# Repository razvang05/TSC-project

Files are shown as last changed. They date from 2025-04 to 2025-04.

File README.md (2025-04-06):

# TSC-project

**Author: Razvan Gheorghe 334CA**

## • Diagrama Bloc
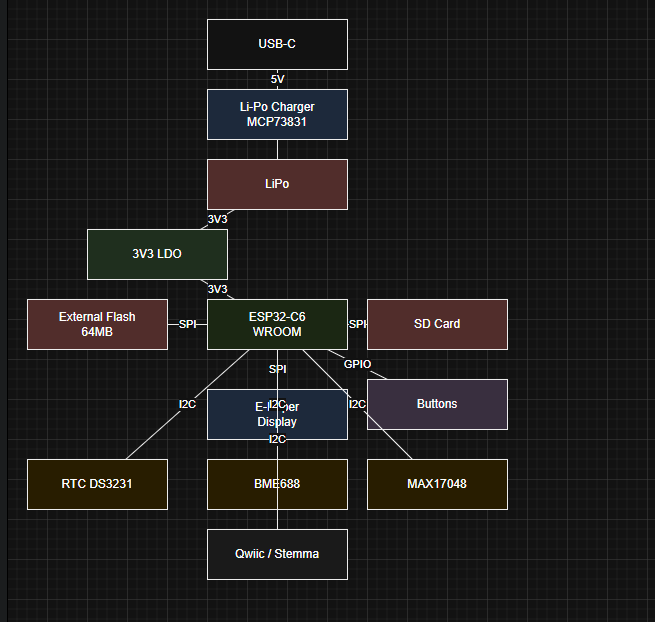
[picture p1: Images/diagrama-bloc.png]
Diagrama Bloc


## • BOM (Bill of Materials)

**Note:** TP-urile au fost construite de mine.

  | Nr. | Component Name | Procurement Link | Datasheet Link |
  |-----|----------------|------------------|----------------|
  | 1 | BOOT_BUTON | [Link](https://www.snapeda.com/parts/EVQP7L01P/Panasonic%20Electronic%20Components/view-part/?welcome=home) | [Datasheet](https://www.snapeda.com/parts/EVQP7L01P/Panasonic/datasheet/) |
  | 2 | C1 | [Link](https://componentsearchengine.com/part-view/CC0402MRX5R5BB106/YAGEO) | [Datasheet](https://componentsearchengine.com/Datasheets/2/CC0402MRX5R5BB106.pdf) |
  | 3 | C1_BAT | [Link](https://componentsearchengine.com/part-view/CC0402MRX5R5BB106/YAGEO) | [Datasheet](https://componentsearchengine.com/Datasheets/2/CC0402MRX5R5BB106.pdf) |
  | 4 | C1_BAT2 | [Link](https://componentsearchengine.com/part-view/CC0402MRX5R5BB106/YAGEO) | [Datasheet](https://componentsearchengine.com/Datasheets/2/CC0402MRX5R5BB106.pdf) |
  | 5 | C2 | [Link](https://componentsearchengine.com/part-view/CC0402MRX5R5BB106/YAGEO) | [Datasheet](https://componentsearchengine.com/Datasheets/2/CC0402MRX5R5BB106.pdf) |
  | 6 | C2_BAT | [Link](https://componentsearchengine.com/part-view/CC0402MRX5R5BB106/YAGEO) | [Datasheet](https://componentsearchengine.com/Datasheets/2/CC0402MRX5R5BB106.pdf) |
  | 7 | C3 | [Link](https://componentsearchengine.com/part-view/CC0402MRX5R5BB106/YAGEO) | [Datasheet](https://componentsearchengine.com/Datasheets/2/CC0402MRX5R5BB106.pdf) |
  | 8 | C4 | [Link](https://componentsearchengine.com/part-view/CC0402MRX5R5BB106/YAGEO) | [Datasheet](https://componentsearchengine.com/Datasheets/2/CC0402MRX5R5BB106.pdf) |
  | 9 | C4_USB | [Link](https://componentsearchengine.com/part-view/CC0402MRX5R5BB106/YAGEO) | [Datasheet](https://componentsearchengine.com/Datasheets/2/CC0402MRX5R5BB106.pdf) |
  | 10 | C5 | [Link](https://componentsearchengine.com/part-view/CC0402MRX5R5BB106/YAGEO) | [Datasheet](https://componentsearchengine.com/Datasheets/2/CC0402MRX5R5BB106.pdf) |
  | 11 | C5_USB | [Link](https://componentsearchengine.com/part-view/CC0402MRX5R5BB106/YAGEO) | [Datasheet](https://componentsearchengine.com/Datasheets/2/CC0402MRX5R5BB106.pdf) |
  | 12 | C6 | [Link](https://componentsearchengine.com/part-view/CC0402MRX5R5BB106/YAGEO) | [Datasheet](https://componentsearchengine.com/Datasheets/2/CC0402MRX5R5BB106.pdf) |
  | 13 | C7 | [Link](https://componentsearchengine.com/part-view/CC0402MRX5R5BB106/YAGEO) | [Datasheet](https://componentsearchengine.com/Datasheets/2/CC0402MRX5R5BB106.pdf) |
  | 14 | C8 | [Link](https://componentsearchengine.com/part-view/CC0402MRX5R5BB106/YAGEO) | [Datasheet](https://componentsearchengine.com/Datasheets/2/CC0402MRX5R5BB106.pdf) |
  | 15 | C9 | [Link](https://componentsearchengine.com/part-view/CC0402MRX5R5BB106/YAGEO) | [Datasheet](https://componentsearchengine.com/Datasheets/2/CC0402MRX5R5BB106.pdf) |
  | 16 | C10 | [Link](https://componentsearchengine.com/part-view/CC0402MRX5R5BB106/YAGEO) | [Datasheet](https://componentsearchengine.com/Datasheets/2/CC0402MRX5R5BB106.pdf) |
  | 17 | C10_SUPERCAR | [Link](https://industry.panasonic.com/global/en/products/control/switch/light-touch/number/evqpuj02k) | [Datasheet](https://industry.panasonic.com/global/en/downloads?tab=catalog&small_g_cd=203&part_no=EVQPUJ02K) |
  | 18 | CHANGE_BUTTON | [Link](https://www.snapeda.com/parts/EVQP7L01P/Panasonic%20Electronic%20Components/view-part/?welcome=home) | [Datasheet](https://www.snapeda.com/parts/EVQP7L01P/Panasonic/datasheet/) |
  | 19 | C_DELAY | [Link](https://componentsearchengine.com/part-view/CC0402MRX5R5BB106/YAGEO) | [Datasheet](https://componentsearchengine.com/Datasheets/2/CC0402MRX5R5BB106.pdf) |
  | 20 | D1 | [Link](https://www.snapeda.com/parts/USBLC6-2SC6Y/STMicroelectronics/view-part/?ref=eda) | [Datasheet](https://www.snapeda.com/parts/USBLC6-2SC6Y/STMicroelectronics/view-part/?ref=eda) |
  | 21 | D2 | [Link](https://ro.mouser.com/ProductDetail/KYOCERA-AVX/SD0805S020S1R0?qs=jCA%252BPfw4LHbpkAoSnwrdjw%3D%3D) | [Datasheet](https://ro.mouser.com/datasheet/2/40/schottky-3165252.pdf) |
  | 22 | D3 | [Link](https://ro.mouser.com/ProductDetail/KYOCERA-AVX/SD0805S020S1R0?qs=jCA%252BPfw4LHbpkAoSnwrdjw%3D%3D) | [Datasheet](https://ro.mouser.com/datasheet/2/40/schottky-3165252.pdf) |
  | 23 | D4 | [Link](https://ro.mouser.com/ProductDetail/KYOCERA-AVX/SD0805S020S1R0?qs=jCA%252BPfw4LHbpkAoSnwrdjw%3D%3D) | [Datasheet](https://ro.mouser.com/datasheet/2/40/schottky-3165252.pdf) |
  | 24 | D5 | [Link](https://ro.mouser.com/ProductDetail/KYOCERA-AVX/SD0805S020S1R0?qs=jCA%252BPfw4LHbpkAoSnwrdjw%3D%3D) | [Datasheet](https://ro.mouser.com/datasheet/2/40/schottky-3165252.pdf) |
  | 25 | D6 | [Link](https://www.snapeda.com/parts/PGB1010603MR/Littelfuse/view-part/?ref=eda) | [Datasheet](https://www.snapeda.com/parts/PGB1010603MR/Littelfuse%20Inc./datasheet/) |
  | 26 | D7 | [Link](https://ro.mouser.com/ProductDetail/KYOCERA-AVX/SD0805S020S1R0?qs=jCA%252BPfw4LHbpkAoSnwrdjw%3D%3D) | [Datasheet](https://ro.mouser.com/datasheet/2/40/schottky-3165252.pdf) |
  | 27 | D8 | [Link](https://www.snapeda.com/parts/PGB1010603MR/Littelfuse/view-part/?ref=eda) | [Datasheet](https://www.snapeda.com/parts/PGB1010603MR/Littelfuse%20Inc./datasheet/) |
  | 28 | D9 | [Link](https://www.snapeda.com/parts/PGB1010603MR/Littelfuse/view-part/?ref=eda) | [Datasheet](https://www.snapeda.com/parts/PGB1010603MR/Littelfuse%20Inc./datasheet/) |
  | 29 | D10 | [Link](https://www.snapeda.com/parts/PGB1010603MR/Littelfuse/view-part/?ref=eda) | [Datasheet](https://www.snapeda.com/parts/PGB1010603MR/Littelfuse%20Inc./datasheet/) |
  | 30 | D11 | [Link](https://www.snapeda.com/parts/PGB1010603MR/Littelfuse/view-part/?ref=eda) | [Datasheet](https://www.snapeda.com/parts/PGB1010603MR/Littelfuse%20Inc./datasheet/) |
  | 31 | D12 | [Link](https://www.snapeda.com/parts/PGB1010603MR/Littelfuse/view-part/?ref=eda) | [Datasheet](https://www.snapeda.com/parts/PGB1010603MR/Littelfuse%20Inc./datasheet/) |
  | 32 | EPD_C1 | [Link](https://componentsearchengine.com/part-view/CC0402MRX5R5BB106/YAGEO) | [Datasheet](https://componentsearchengine.com/Datasheets/2/CC0402MRX5R5BB106.pdf) |
  | 33 | EPD_C2 | [Link](https://componentsearchengine.com/part-view/CC0402MRX5R5BB106/YAGEO) | [Datasheet](https://componentsearchengine.com/Datasheets/2/CC0402MRX5R5BB106.pdf) |
  | 34 | EPD_C5 | [Link](https://componentsearchengine.com/part-view/CC0402MRX5R5BB106/YAGEO) | [Datasheet](https://componentsearchengine.com/Datasheets/2/CC0402MRX5R5BB106.pdf) |
  | 35 | EPD_C6 | [Link](https://componentsearchengine.com/part-view/CC0402MRX5R5BB106/YAGEO) | [Datasheet](https://componentsearchengine.com/Datasheets/2/CC0402MRX5R5BB106.pdf) |
  | 36 | EPD_C7 | [Link](https://componentsearchengine.com/part-view/CC0402MRX5R5BB106/YAGEO) | [Datasheet](https://componentsearchengine.com/Datasheets/2/CC0402MRX5R5BB106.pdf) |
  | 37 | EPD_C8 | [Link](https://componentsearchengine.com/part-view/CC0402MRX5R5BB106/YAGEO) | [Datasheet](https://componentsearchengine.com/Datasheets/2/CC0402MRX5R5BB106.pdf) |
  | 38 | EPD_C9 | [Link](https://componentsearchengine.com/part-view/CC0402MRX5R5BB106/YAGEO) | [Datasheet](https://componentsearchengine.com/Datasheets/2/CC0402MRX5R5BB106.pdf) |
  | 39 | EPD_C10 | [Link](https://componentsearchengine.com/part-view/CC0402MRX5R5BB106/YAGEO) | [Datasheet](https://componentsearchengine.com/Datasheets/2/CC0402MRX5R5BB106.pdf) |
  | 40 | EPD_C11 | [Link](https://componentsearchengine.com/part-view/CC0402MRX5R5BB106/YAGEO) | [Datasheet](https://componentsearchengine.com/Datasheets/2/CC0402MRX5R5BB106.pdf) |
  | 41 | EPD_C12 | [Link](https://componentsearchengine.com/part-view/CC0402MRX5R5BB106/YAGEO) | [Datasheet](https://componentsearchengine.com/Datasheets/2/CC0402MRX5R5BB106.pdf) |
  | 42 | IC1 | [Link](https://componentsearchengine.com/part-view/BD5229G-TR/ROHM%20Semiconductor) | [Datasheet](https://datasheet.datasheetarchive.com/originals/distributors/Datasheets_SAMA/f2b9741ef86007909f138d561a359946.pdf) |
  | 43 | IC4 | [Link](https://componentsearchengine.com/part-view/XC6220A331MR-G/Torex) | [Datasheet](https://product.torexsemi.com/system/files/series/xc6220.pdf) |
  | 44 | J1 | [Link](https://componentsearchengine.com/part-view/FH34SRJ-24S-0.5SH(99)/Hirose) | [Datasheet](https://www.hirose.com/en/product/document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) |
  | 45 | J2 | [Link](https://componentsearchengine.com/part-view/USB4110-GF-A/GCT%20(GLOBAL%20CONNECTOR%20TECHNOLOGY)) | [Datasheet](https://gct.co/files/drawings/usb4110.pdf) |
  | 46 | J3 | [Link](https://www.snapeda.com/parts/PRT-14417/SparkFun/view-part/) | [Datasheet](https://www.snapeda.com/parts/PRT-14417/SparkFun%20Electronics/datasheet/) |
  | 47 | J4 | [Link](https://www.snapeda.com/parts/112A-TAAR-R03/Attend/view-part/) | [Datasheet](https://www.snapeda.com/parts/112A-TAAR-R03/Attend/datasheet/) |
  | 48 | MCP73831 | [Link](https://ro.mouser.com/ProductDetail/Microchip-Technology/MCP73831T-2ACI-OT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) | [Datasheet](https://ro.mouser.com/datasheet/2/268/MCP73831_Family_Data_Sheet_DS20001984H-3441711.pdf) |
  | 49 | L1 | [Link](https://ro.mouser.com/ProductDetail/Wurth-Elektronik/744043680?qs=PGXP4M47uW6VkZq%252BkzjrHA%3D%3D) | [Datasheet](https://www.we-online.com/components/products/datasheet/744043680.pdf) |
  | 50 | PFMF.050.1 | [Link](https://ro.mouser.com/ProductDetail/EPCOS-TDK/B72520T0350K062?qs=dEfas%2FXlABIszF52uu7vrg%3D%3D) | [Datasheet](https://www.tdk-electronics.tdk.com/inf/75/db/CTVS_14/Surge_protection_series.pdf) |
  | 51 | Q1 | [Link](https://componentsearchengine.com/part-view/DMG2305UX-7/Diodes%20Incorporated) | [Datasheet](https://www.diodes.com//assets/Datasheets/DMG2305UX.pdf) |
  | 52 | Q2 | [Link](https://componentsearchengine.com/part-view/DMG2305UX-7/Diodes%20Incorporated) | [Datasheet](https://www.diodes.com//assets/Datasheets/DMG2305UX.pdf) |
  | 53 | Q3 | [Link](https://componentsearchengine.com/part-view/SI1308EDL-T1-GE3/Vishay) | [Datasheet](https://componentsearchengine.com/part-view/SI1308EDL-T1-GE3/Vishay) |
  | 54 | R1 | [Link](https://componentsearchengine.com/part-view/R0402%201%25%20100%20K%20(RC0402FR-07100KL)/YAGEO) | [Datasheet](https://www.yageo.com/upload/media/product/products/datasheet/rchip/PYu-RC_Group_51_RoHS_L_12.pdf) |
  | 55 | R1_PINH | [Link](https://componentsearchengine.com/part-view/R0402%201%25%20100%20K%20(RC0402FR-07100KL)/YAGEO) | [Datasheet](https://www.yageo.com/upload/media/product/products/datasheet/rchip/PYu-RC_Group_51_RoHS_L_12.pdf) |
  | 56 | R1_PINH1 | [Link](https://componentsearchengine.com/part-view/R0402%201%25%20100%20K%20(RC0402FR-07100KL)/YAGEO) | [Datasheet](https://www.yageo.com/upload/media/product/products/datasheet/rchip/PYu-RC_Group_51_RoHS_L_12.pdf) |
  | 57 | R1_BAT | [Link](https://componentsearchengine.com/part-view/R0402%201%25%20100%20K%20(RC0402FR-07100KL)/YAGEO) | [Datasheet](https://www.yageo.com/upload/media/product/products/datasheet/rchip/PYu-RC_Group_51_RoHS_L_12.pdf) |
  | 58 | R1_PWRUSB | [Link](https://componentsearchengine.com/part-view/R0402%201%25%20100%20K%20(RC0402FR-07100KL)/YAGEO) | [Datasheet](https://www.yageo.com/upload/media/product/products/datasheet/rchip/PYu-RC_Group_51_RoHS_L_12.pdf) |
  | 59 | R2 | [Link](https://componentsearchengine.com/part-view/R0402%201%25%20100%20K%20(RC0402FR-07100KL)/YAGEO) | [Datasheet](https://www.yageo.com/upload/media/product/products/datasheet/rchip/PYu-RC_Group_51_RoHS_L_12.pdf) |
  | 60 | R2_PINH | [Link](https://componentsearchengine.com/part-view/R0402%201%25%20100%20K%20(RC0402FR-07100KL)/YAGEO) | [Datasheet](https://www.yageo.com/upload/media/product/products/datasheet/rchip/PYu-RC_Group_51_RoHS_L_12.pdf) |
  | 61 | R2-PINH1 | [Link](https://componentsearchengine.com/part-view/R0402%201%25%20100%20K%20(RC0402FR-07100KL)/YAGEO) | [Datasheet](https://www.yageo.com/upload/media/product/products/datasheet/rchip/PYu-RC_Group_51_RoHS_L_12.pdf) |
  | 62 | R2 | [Link](https://componentsearchengine.com/part-view/R0402%201%25%20100%20K%20(RC0402FR-07100KL)/YAGEO) | [Datasheet](https://www.yageo.com/upload/media/product/products/datasheet/rchip/PYu-RC_Group_51_RoHS_L_12.pdf) |
  | 63 | R2-PINH | [Link](https://componentsearchengine.com/part-view/R0402%201%25%20100%20K%20(RC0402FR-07100KL)/YAGEO) | [Datasheet](https://www.yageo.com/upload/media/product/products/datasheet/rchip/PYu-RC_Group_51_RoHS_L_12.pdf) |
  | 64 | R2-PINH1 | [Link](https://componentsearchengine.com/part-view/R0402%201%25%20100%20K%20(RC0402FR-07100KL)/YAGEO) | [Datasheet](https://www.yageo.com/upload/media/product/products/datasheet/rchip/PYu-RC_Group_51_RoHS_L_12.pdf) |
  | 65 | R2_USB | [Link](https://componentsearchengine.com/part-view/R0402%201%25%20100%20K%20(RC0402FR-07100KL)/YAGEO) | [Datasheet](https://www.yageo.com/upload/media/product/products/datasheet/rchip/PYu-RC_Group_51_RoHS_L_12.pdf) |
  | 66 | R2_USB | [Link](https://componentsearchengine.com/part-view/R0402%201%25%20100%20K%20(RC0402FR-07100KL)/YAGEO) | [Datasheet](https://www.yageo.com/upload/media/product/products/datasheet/rchip/PYu-RC_Group_51_RoHS_L_12.pdf) |
  | 67 | R2_USB1 | [Link](https://componentsearchengine.com/part-view/R0402%201%25%20100%20K%20(RC0402FR-07100KL)/YAGEO) | [Datasheet](https://www.yageo.com/upload/media/product/products/datasheet/rchip/PYu-RC_Group_51_RoHS_L_12.pdf) |
  | 68 | R3 | [Link](https://componentsearchengine.com/part-view/R0402%201%25%20100%20K%20(RC0402FR-07100KL)/YAGEO) | [Datasheet](https://www.yageo.com/upload/media/product/products/datasheet/rchip/PYu-RC_Group_51_RoHS_L_12.pdf) |
  | 69 | R4 | [Link](https://componentsearchengine.com/part-view/R0402%201%25%20100%20K%20(RC0402FR-07100KL)/YAGEO) | [Datasheet](https://www.yageo.com/upload/media/product/products/datasheet/rchip/PYu-RC_Group_51_RoHS_L_12.pdf) |
  | 70 | R5 | [Link](https://componentsearchengine.com/part-view/R0402%201%25%20100%20K%20(RC0402FR-07100KL)/YAGEO) | [Datasheet](https://www.yageo.com/upload/media/product/products/datasheet/rchip/PYu-RC_Group_51_RoHS_L_12.pdf) |
  | 71 | R6 | [Link](https://componentsearchengine.com/part-view/R0402%201%25%20100%20K%20(RC0402FR-07100KL)/YAGEO) | [Datasheet](https://www.yageo.com/upload/media/product/products/datasheet/rchip/PYu-RC_Group_51_RoHS_L_12.pdf) |
  | 72 | R7 | [Link](https://componentsearchengine.com/part-view/R0402%201%25%20100%20K%20(RC0402FR-07100KL)/YAGEO) | [Datasheet](https://www.yageo.com/upload/media/product/products/datasheet/rchip/PYu-RC_Group_51_RoHS_L_12.pdf) |
  | 73 | R8 | [Link](https://componentsearchengine.com/part-view/R0402%201%25%20100%20K%20(RC0402FR-07100KL)/YAGEO) | [Datasheet](https://www.yageo.com/upload/media/product/products/datasheet/rchip/PYu-RC_Group_51_RoHS_L_12.pdf) |
  | 74 | R9 | [Link](https://componentsearchengine.com/part-view/R0402%201%25%20100%20K%20(RC0402FR-07100KL)/YAGEO) | [Datasheet](https://www.yageo.com/upload/media/product/products/datasheet/rchip/PYu-RC_Group_51_RoHS_L_12.pdf) |
  | 75 | R10 | [Link](https://componentsearchengine.com/part-view/R0402%201%25%20100%20K%20(RC0402FR-07100KL)/YAGEO) | [Datasheet](https://www.yageo.com/upload/media/product/products/datasheet/rchip/PYu-RC_Group_51_RoHS_L_12.pdf) |
  | 76 | RESET_BUTTON | [Link](https://www.snapeda.com/parts/EVQP7L01P/Panasonic%20Electronic%20Components/view-part/?welcome=home) | [Datasheet](https://www.snapeda.com/parts/EVQP7L01P/Panasonic/datasheet/) |
  | 77 | R_BOOT | [Link](https://componentsearchengine.com/part-view/R0402%201%25%20100%20K%20(RC0402FR-07100KL)/YAGEO) | [Datasheet](https://www.yageo.com/upload/media/product/products/datasheet/rchip/PYu-RC_Group_51_RoHS_L_12.pdf) |
  | 78 | R_CAPACITOR | [Link](https://componentsearchengine.com/part-view/R0402%201%25%20100%20K%20(RC0402FR-07100KL)/YAGEO) | [Datasheet](https://www.yageo.com/upload/media/product/products/datasheet/rchip/PYu-RC_Group_51_RoHS_L_12.pdf) |
  | 79 | R_CHANGE | [Link](https://componentsearchengine.com/part-view/R0402%201%25%20100%20K%20(RC0402FR-07100KL)/YAGEO) | [Datasheet](https://www.yageo.com/upload/media/product/products/datasheet/rchip/PYu-RC_Group_51_RoHS_L_12.pdf) |
  | 80 | R_CL1 | [Link](https://componentsearchengine.com/part-view/R0402%201%25%20100%20K%20(RC0402FR-07100KL)/YAGEO) | [Datasheet](https://www.yageo.com/upload/media/product/products/datasheet/rchip/PYu-RC_Group_51_RoHS_L_12.pdf) |
  | 81 | R_RESET | [Link](https://componentsearchengine.com/part-view/R0402%201%25%20100%20K%20(RC0402FR-07100KL)/YAGEO) | [Datasheet](https://www.yageo.com/upload/media/product/products/datasheet/rchip/PYu-RC_Group_51_RoHS_L_12.pdf) |
  | 82 | SENSOR2 | [Link](https://www.snapeda.com/parts/BME680/Bosch/view-part/?welcome=home) | [Datasheet](https://www.snapeda.com/parts/BME680/Bosch%20Sensortec/datasheet/) |
  | 83 | SJ1 | [Link](https://grabcad.com/library/solder-jumpers-1) | [Datasheet](https://grabcad.com/library/solder-jumpers-1) |
  | 84 | TP1 | [Link](nan) | [Datasheet](nan) |
  | 85 | TP2 | [Link](nan) | [Datasheet](nan) |
  | 86 | TP3 | [Link](nan) | [Datasheet](nan) |
  | 87 | TP4 | [Link](nan) | [Datasheet](nan) |
  | 88 | TP5 | [Link](nan) | [Datasheet](nan) |
  | 89 | TP6 | [Link](nan) | [Datasheet](nan) |
  | 90 | TP7 | [Link](nan) | [Datasheet](nan) |
  | 91 | TP8 | [Link](nan) | [Datasheet](nan) |
  | 92 | TP9 | [Link](nan) | [Datasheet](nan) |
  | 93 | TP10 | [Link](nan) | [Datasheet](nan) |
  | 94 | TP11 | [Link](nan) | [Datasheet](nan) |
  | 95 | TP12 | [Link](nan) | [Datasheet](nan) |
  | 96 | TP13 | [Link](nan) | [Datasheet](nan) |
  | 97 | TP14 | [Link](nan) | [Datasheet](nan) |
  | 98 | TP15 | [Link](nan) | [Datasheet](nan) |
  | 99 | TP16 | [Link](nan) | [Datasheet](nan) |
  | 100 | TP17 | [Link](nan) | [Datasheet](nan) |
  | 101 | U1 | [Link](https://www.snapeda.com/parts/W25Q512JVEIQ/Winbond+Electronics/view-part/?ref=eda) | [Datasheet](https://www.snapeda.com/parts/W25Q512JVEIQ/Winbond+Electronics/view-part/?ref=eda) |
  | 102 | U2 | [Link](https://www.snapeda.com/parts/ESP32-C6-WROOM-1-N8/Espressif+Systems/view-part/?ref=eda) | [Datasheet](https://www.snapeda.com/parts/ESP32-C6-WROOM-1-N8/Espressif%20Systems/datasheet/) |
  | 103 | U3 | [Link](https://www.snapeda.com/parts/DS3231SN%23/Analog+Devices/view-part/?ref=eda) | [Datasheet](https://www.snapeda.com/parts/DS3231SN%23/Analog%20Devices/datasheet/) |
  | 104 | U4 | [Link](https://www.snapeda.com/parts/MAX17048G+T10/Analog+Devices/view-part/?ref=eda) | [Datasheet](https://www.snapeda.com/parts/MAX17048G+T10/Analog%20Devices/datasheet/) |

  ## ⚙️ Hardware Functionality Description

Dispozitivul eBook Reader este un sistem portabil de citire a cărților electronice, construit în jurul modulului **ESP32-C6-WROOM-1-N8**. Acesta integrează următoarele componente și module:

### 🔌 Module și Funcționalitate

- **ESP32-C6-WROOM-1-N8** — Microcontroler principal cu Wi-Fi și BLE integrat; gestionează comunicația, senzorii și afișajul.
- **BME688** — Senzor de calitate a aerului și mediu (temperatură, umiditate, presiune, gaz); conectat prin magistrala **I2C**.
- **DS3231SN** — Modul RTC de înaltă precizie pentru menținerea timpului real; conectat la ESP32 prin **I2C**.
- **MAX17048** — Monitor de nivel al bateriei cu interfață **I2C**, oferă estimarea SOC (state of charge).
- **SD Card Module** — Pentru stocarea locală a datelor colectate; conectat prin **SPI**.
- **Display E-Ink** — Afișaj cu consum redus de energie, interfață **SPI**, include semnale EPD_CS, EPD_DC, EPD_RST, EPD_BUSY.
- **Memorie NOR Flash W25Q512JVEIQ (64MB)** — Conectată prin **SPI** pentru stocarea firmware-ului sau datelor mari.
- **Buton BOOT și RESET** — Control GPIO pentru bootloader și resetare sistem.
- **MCP73831** — Controler pentru încărcare acumulator Li-Po, conectat direct la baterie.
- **LDO XC6220A331MR-G** — Regulator de tensiune 3.3V pentru alimentarea circuitelor logice.
- **Port USB-C (USB4110-GF-A)** — Alimentare și interfață serială pentru upload cod și debugging.

### 🔧 Interfețe de Comunicație

| Interfață | Componente conectate |
|---|---|
| I2C | BME688, MAX17048, DS3231SN |
| SPI | E-Ink Display, SD Card, Flash Memory |
| UART | Serial debug prin USB-C (TX/RX) |
| GPIO | Butoane, LED-uri, semnale control |

### ⚡ Energie și Alimentare

- Alimentarea se face prin **USB-C** sau baterie Li-Po.
- Planul de masă este aplicat pe ambele straturi (TOP & BOTTOM).
- Se folosesc **condensatori de decuplare 100nF** aproape de fiecare pin de alimentare al IC-urilor.
- Regulatorul LDO oferă 3.3V, iar controlerul MCP73831 gestionează încărcarea bateriei.
- Funcțiile de **low-power sleep** ale ESP32 sunt folosite pentru a reduce consumul în standby.

## 📌 ESP32-C6 Pin Mapping

| Pin ESP32-C6 | Componentă Legată | Funcție |
|---|---|---|
| GPIO0 | Flash Memory (DI) | SPI MOSI |
| GPIO1 | Flash Memory (DO) | SPI MISO |
| GPIO2 | Flash CS | Chip Select |
| GPIO3 | Flash HOLD | Hold/Reset |
| GPIO6 | E-Ink Display (EPD_DC)  | Data/Command Select  |
| GPIO7 | E-Ink Display (EPD_CS)  | Chip Select |
| GPIO8 | E-Ink Display (EPD_RST) | Reset |
| GPIO9 | E-Ink Display (BUSY) | Status Feedback |
| GPIO10 | SD Card (CS) | Chip Select |
| GPIO11 | SD Card (MOSI) | Data In |
| GPIO12 | SD Card (MISO) | Data Out |
| GPIO13 | SD Card (CLK) | Clock |
| GPIO16/17 | UART | Serial TX / RX |
| GPIO18/19 | I2C | SDA / SCL |
| GPIO20 | MAX17048 Alert | Battery Warning |

## 🧩 Alte Elemente Relevante pentru Review

- **Design Log**: Înregistrări ale deciziilor de proiectare, erori întâlnite și soluții aplicate.
- **Imagini randate 3D**: Prezentate în folderul `Images/` și în secțiunea `Mechanical/`.
- **Plasarea componentelor**: Respectă fișierul de recomandări mecanice, inclusiv alinierea cu carcasa.
- **Carcasa și Modelul 3D**: Include model complet în Fusion360 și export `.step`, în `Mechanical/`.
- **Test Pad-uri**: Clar etichetate în silkscreen, prezente pentru semnalele relevante (MOSI, MISO, Rx, etc.).
- **Silkscreen**: Numele componentelor sunt vizibile și nu sunt suprapuse peste pad-uri.

---

> Toate aceste aspecte sunt conforme cu cerințele OpenBook și ghidurile din laborator. Design-ul a fost verificat prin ERC & DRC, cu toate erorile relevante rezolvate.

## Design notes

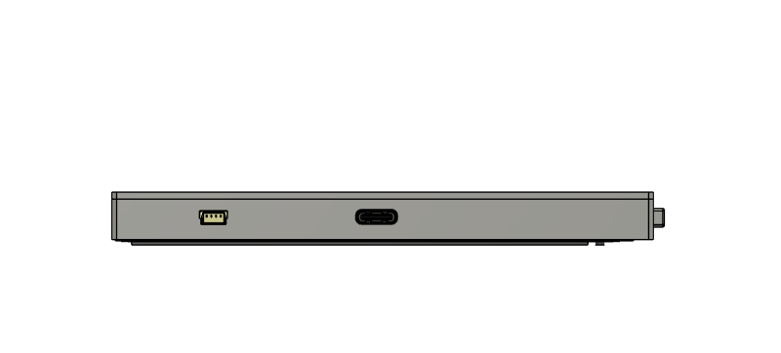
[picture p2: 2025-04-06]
Images/right.png

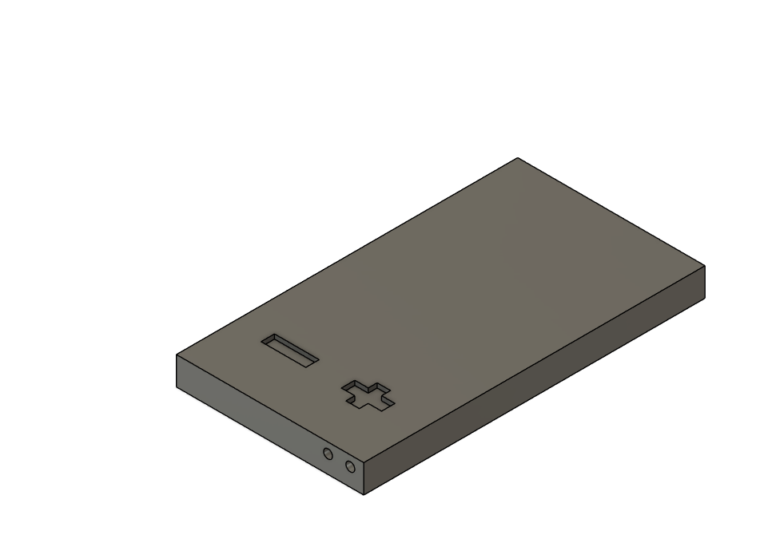
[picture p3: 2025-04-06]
Images/battery.png

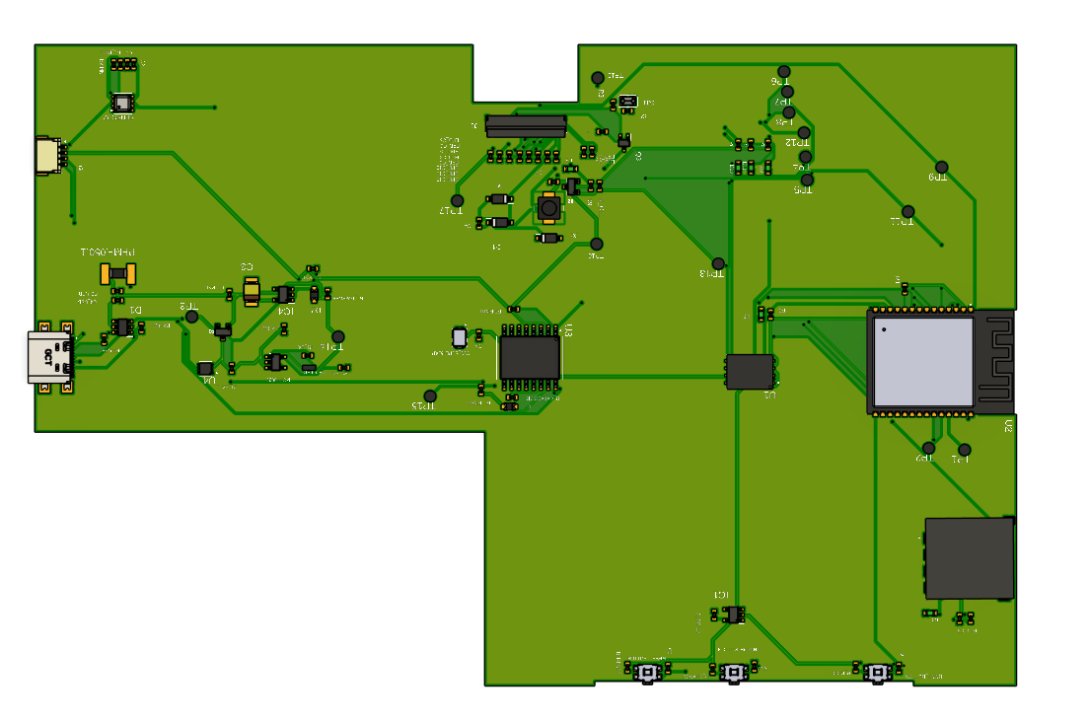
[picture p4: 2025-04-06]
Images/pcb_top.png

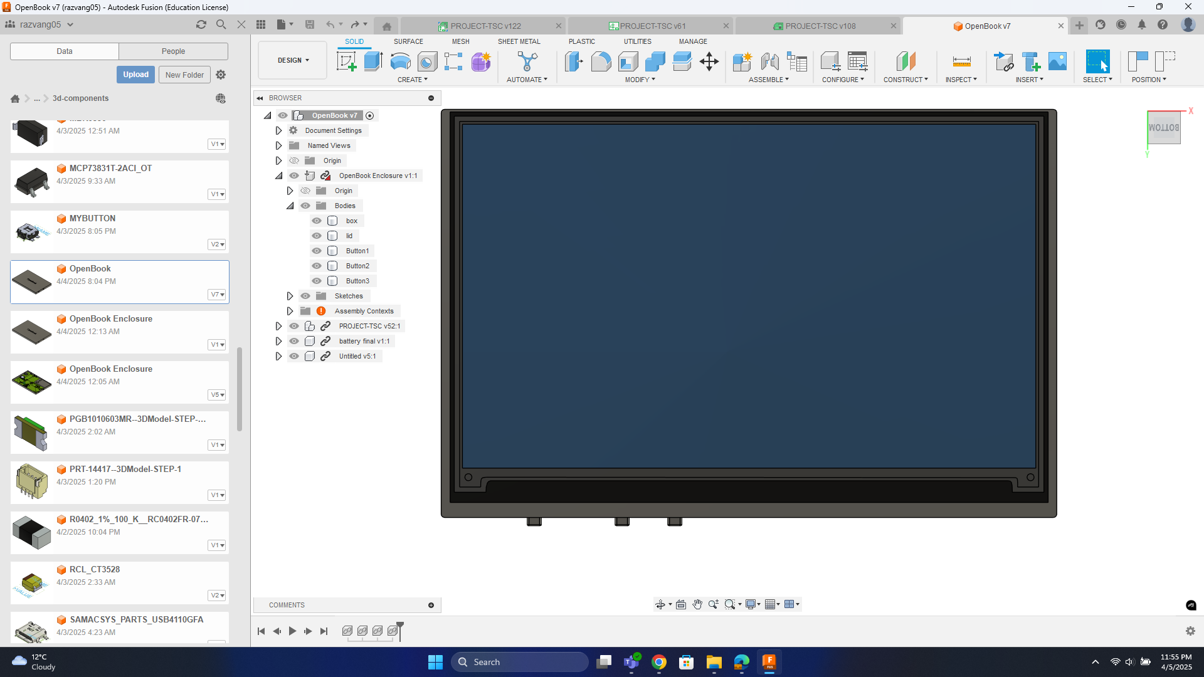
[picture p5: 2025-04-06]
Images/bottom_ebook.png

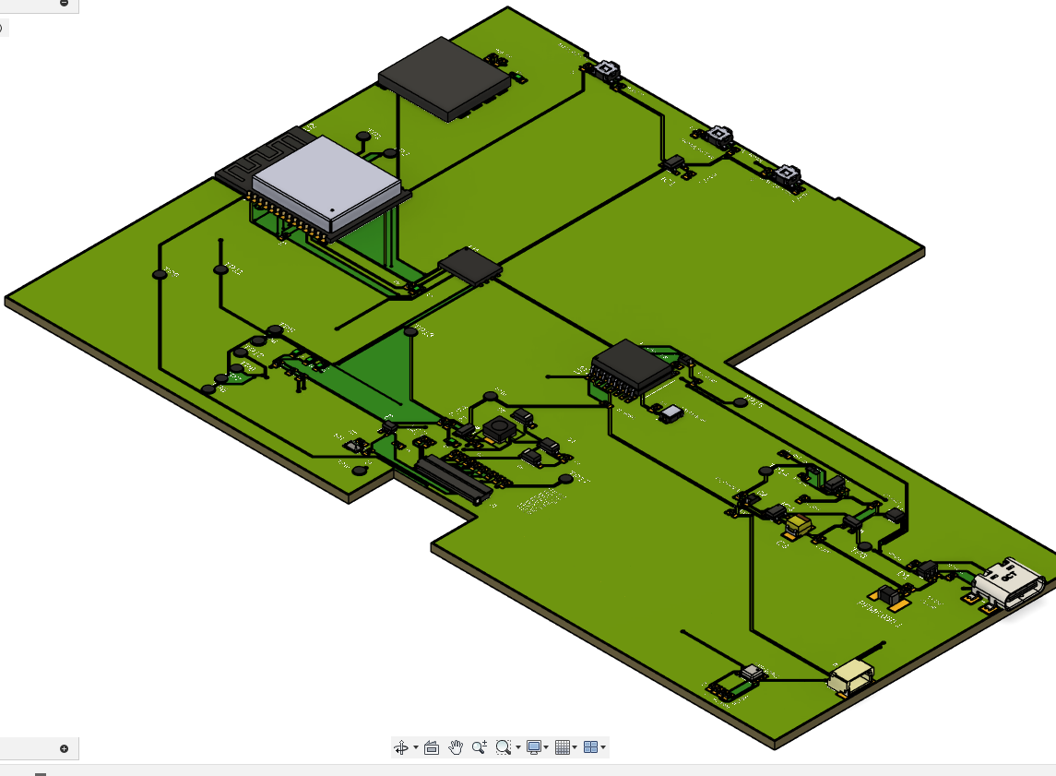
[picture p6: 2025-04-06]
Images/pcb.png

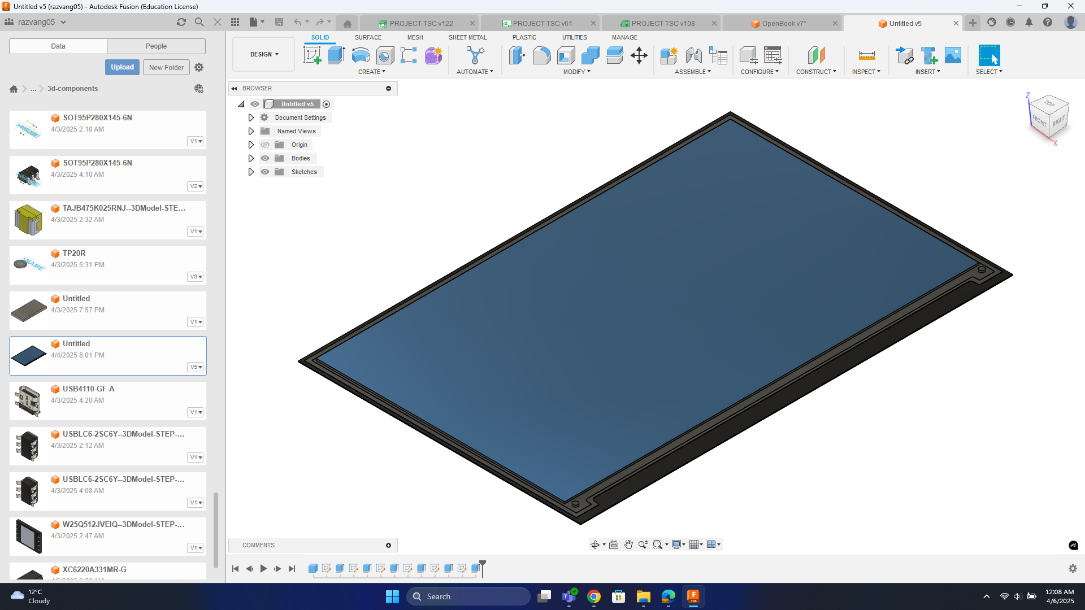
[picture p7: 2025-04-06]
Images/display.png

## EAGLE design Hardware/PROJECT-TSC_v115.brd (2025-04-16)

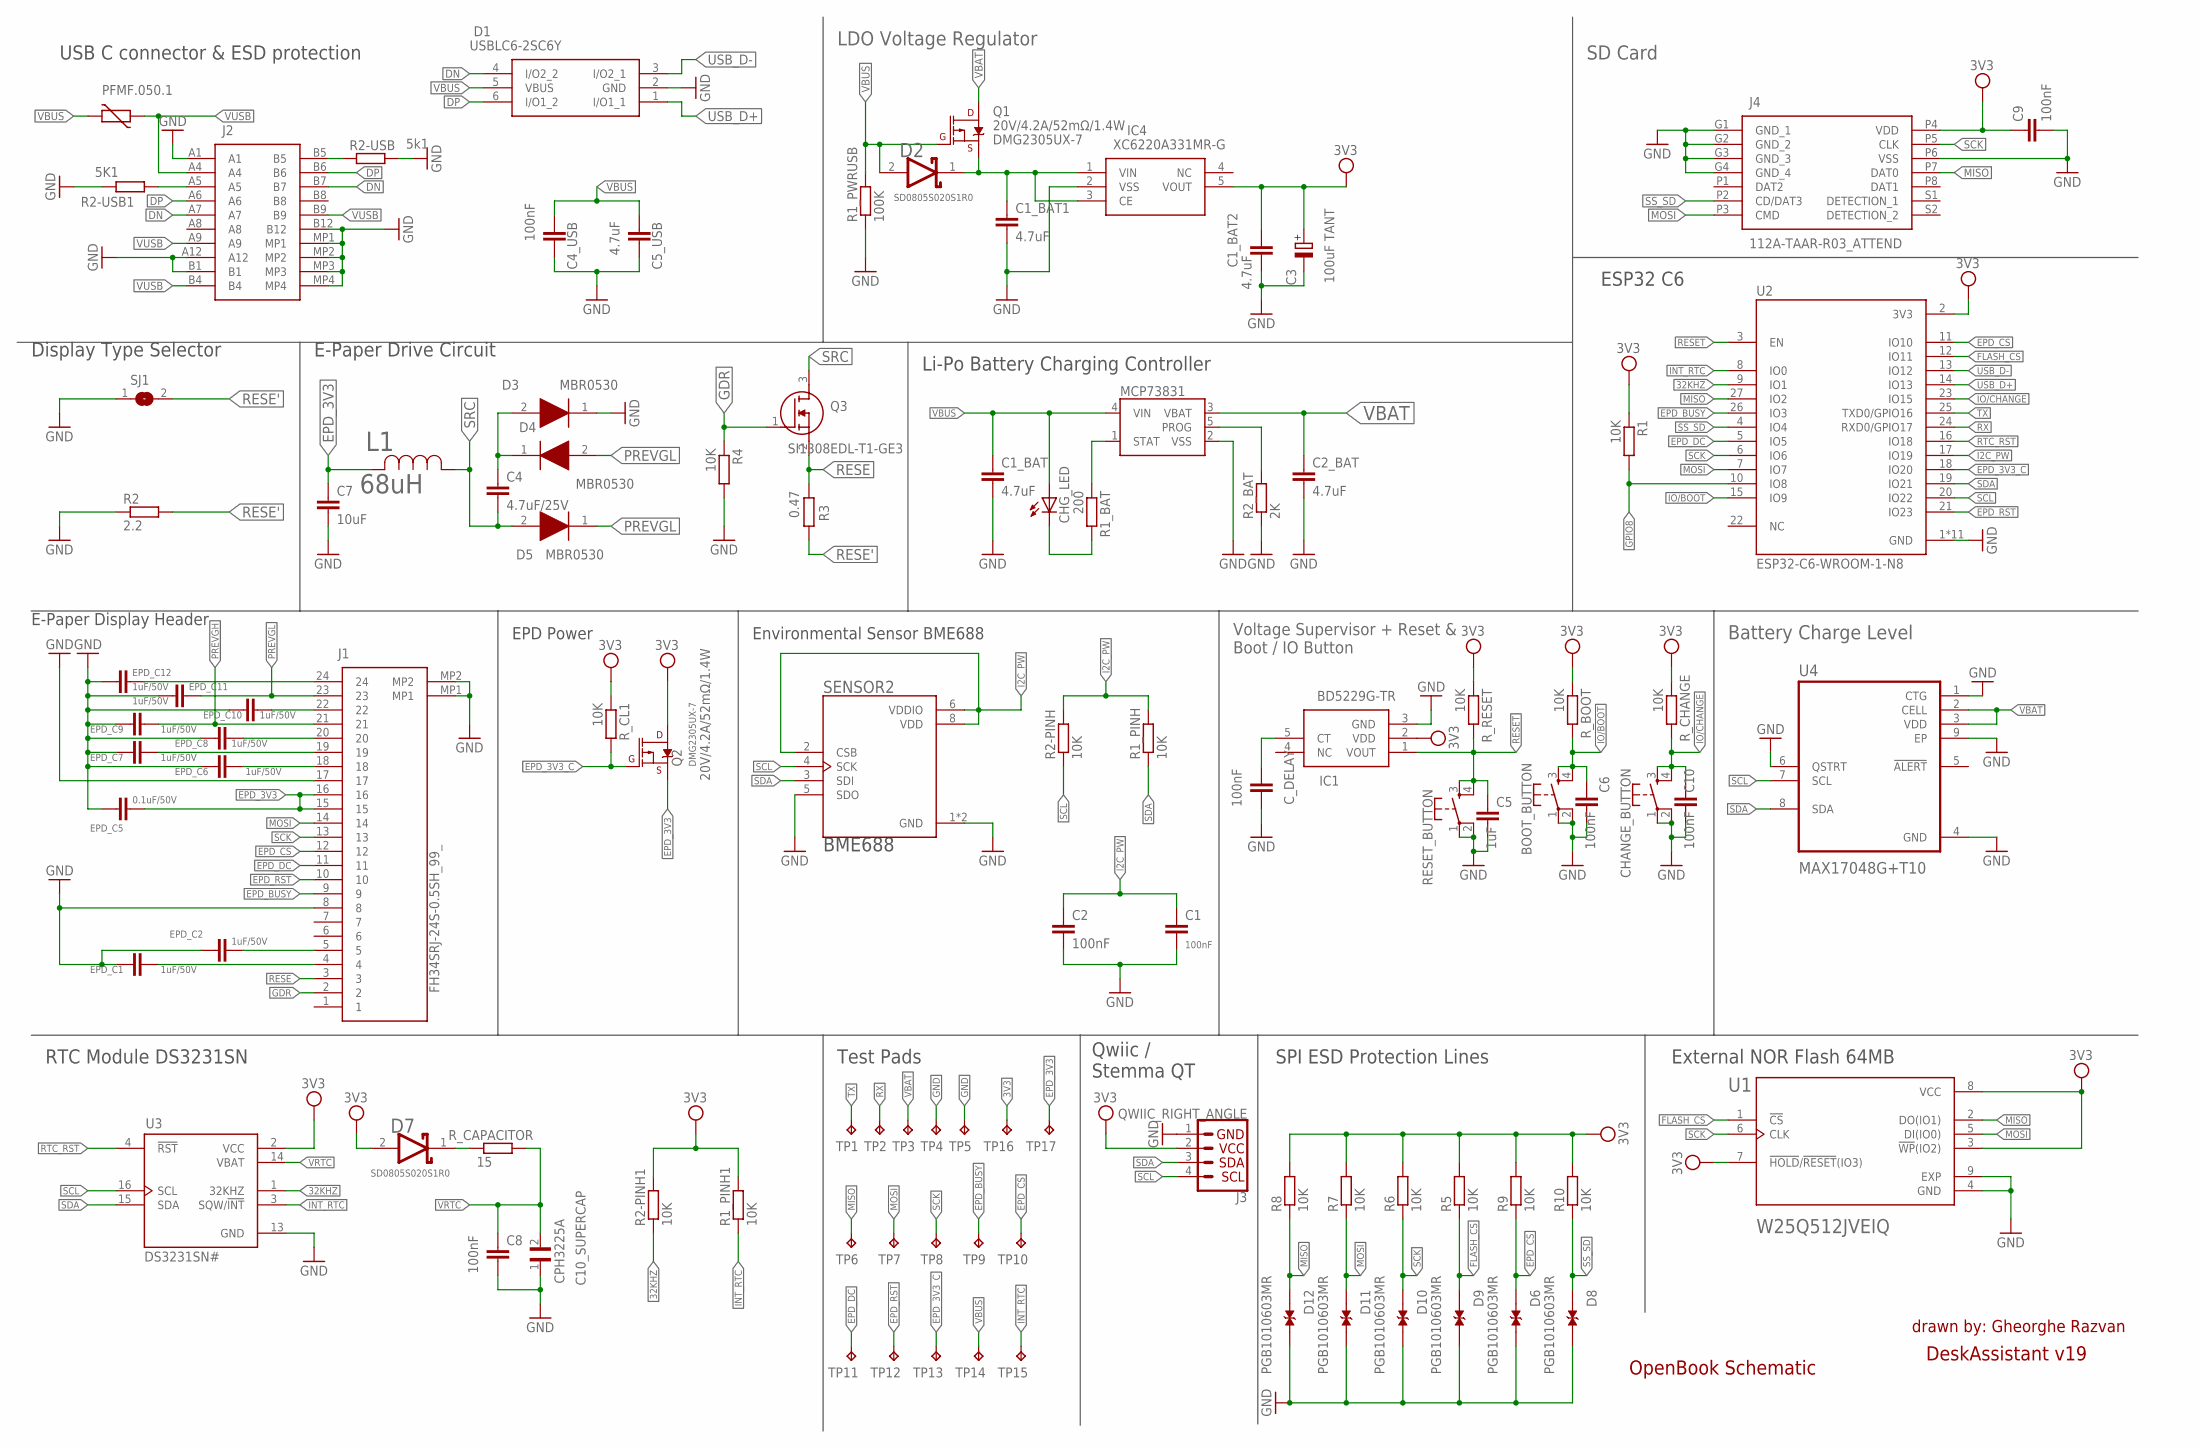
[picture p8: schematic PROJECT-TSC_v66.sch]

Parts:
BOOT_BUTTON: BUTTON_CUSYOMV1; MYBUTTON
C1, C2, C4_USB, C6, C8, C9, C10: 100nF; EAGLE-LTSPICE_C0402
C1_BAT, C1_BAT1, C1_BAT2, C2_BAT, C5_USB: 4.7uF; EAGLE-LTSPICE_C0402
C3: 100uF TANT; RCL_CT3528
C4: 4.7uF/25V; EAGLE-LTSPICE_C0402
C5: 1uF; EAGLE-LTSPICE_C0402
C7: 10uF; EAGLE-LTSPICE_C0402
C10_SUPERCAP: CPH3225A; CAPCP3225X100N
CHANGE_BUTTON: BUTTON_CUSYOMV1; MYBUTTON
CHG_LED: ADAFRUIT_LEDCHIP-LED0603; ADAFRUIT_CHIP-LED0603
C_DELAY: 100nF; EAGLE-LTSPICE_C0402
D1: USBLC6-2SC6Y; SOT95P280X145-6N
D2, D7: ESP32_WROVER_AVX---SD0805S020S1R0_AVX_SD0805S020S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; ESP32_WROVER_AVX---SD0805S020S1R0_AVX_SD0805S020S1R0_0
D3, D4, D5: MBR0530; SOD3716X135N
D6, D8, D9, D10, D11, D12: PGB1010603MR; DIOC1608X36N
EPD_C1, EPD_C2, EPD_C6, EPD_C7, EPD_C8, EPD_C9, EPD_C10, EPD_C11, EPD_C12: 1uF/50V; EAGLE-LTSPICE_C0402
EPD_C5: 0.1uF/50V; EAGLE-LTSPICE_C0402
IC1: BD5229G-TR; SOT95P280X120-5N
IC4: XC6220A331MR-G; SOT95P280X120-5N
J1: FH34SRJ-24S-0.5SH_99_; FH34SRJ24S05SH99
J2: SAMACSYS_PARTS_USB4110-GF-A; SAMACSYS_PARTS_USB4110GFA
J3: QWIIC_RIGHT_ANGLE; JST04_1MM_RA
J4: 112A-TAAR-R03_ATTEND; 112ATAARR03ATTEND
L1: 68uH; IND_4828-WE-TPC_WRE
MCP73831: ESP32_WROVER_SPARKFUN-IC-POWER_MCP73831; ESP32_WROVER_SPARKFUN-IC-POWER_SOT23-5
PFMF.050.1: ESP32C6_VARISTORCN1812; ESP32C6_VARISTOR_CT/CN1812
Q1, Q2: 20V/4.2A/52mΩ/1.4W; ESP32_WROVER_SPARKFUN-DISCRETESEMI_SOT23-3
Q3: SI1308EDL-T1-GE3; SOT65P210X110-3N
R1, R1_PINH, R1_PINH1, R2-PINH, R2-PINH1, R4, R5, R6, R7, R8, R9, R10: 10K; ESP32_WROVER_EAGLE-LTSPICE_R0402
R1_BAT: 200; ESP32_WROVER_EAGLE-LTSPICE_R0402
R1_PWRUSB: 100K; ESP32_WROVER_EAGLE-LTSPICE_R0402
R2: 2.2; ESP32_WROVER_EAGLE-LTSPICE_R0402
R2-USB: 5k1; ESP32_WROVER_EAGLE-LTSPICE_R0402
R2-USB1: 5K1; ESP32_WROVER_EAGLE-LTSPICE_R0402
R2_BAT: 2K; ESP32_WROVER_EAGLE-LTSPICE_R0402
R3: 0.47; ESP32_WROVER_EAGLE-LTSPICE_R0402
RESET_BUTTON: BUTTON_CUSYOMV1; MYBUTTON
R_BOOT: 10K; ESP32_WROVER_EAGLE-LTSPICE_R0402
R_CAPACITOR: 15; ESP32_WROVER_EAGLE-LTSPICE_R0402
R_CHANGE: 10K; ESP32_WROVER_EAGLE-LTSPICE_R0402
R_CL1: 10K; ESP32_WROVER_EAGLE-LTSPICE_R0402
R_RESET: 10K; ESP32_WROVER_EAGLE-LTSPICE_R0402
SENSOR2: ESP32_WROVER_BME680_BME680; ESP32_WROVER_BME680_PSON80P300X300X100-8N
SJ1: SJ
TP1, TP2, TP3, TP4, TP5, TP6, TP7, TP8, TP9, TP10, TP11, TP12, TP13, TP14, TP15, TP16, TP17: TPTP20R; TP20R
U1: W25Q512JVEIQ; SON127P600X800X80-9N
U2: ESP32-C6-WROOM-1-N8; XCVR_ESP32-C6-WROOM-1-N8
U3: DS3231SN#; SOIC127P1032X265-16N
U4: MAX17048G+T10; SON50P200X200X80-9N

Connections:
3V3: C1_BAT2.1, C3.+, C9.1, D7.2 (ANODE), IC1.2 (VDD), IC4.5 (VOUT), J3.2, J4.P4 (VDD), Q2.3 (D), R1.1, R1_PINH1.2, R2-PINH1.2, R5.2, R6.2, R7.2, R8.2, R9.2, R10.2, R_BOOT.1, R_CHANGE.1, R_CL1.1, R_RESET.1, TP16.TP, U1.3 (!WP!(IO2)), U1.7 (!HOLD!/!RESET!(IO3)), U1.8 (VCC), U2.2 (3V3), U3.2 (VCC)
32KHZ: R2-PINH1.1, U2.9 (IO1), U3.1 (32KHZ)
DN: D1.4 (I/O2_2), J2.A7, J2.B7
DP: D1.6 (I/O1_2), J2.A6, J2.B6
EPD_3V3: C7.1, EPD_C5.1, J1.15, J1.16, L1.2, Q2.2 (S), TP17.TP
EPD_3V3_C: Q2.1 (G), R_CL1.2, TP13.TP, U2.18 (IO20)
EPD_BUSY: J1.9, TP9.TP, U2.26 (IO3)
EPD_CS: D6.1, J1.12, R9.1, TP10.TP, U2.11 (IO10)
EPD_DC: J1.11, TP11.TP, U2.5 (IO5)
EPD_RST: J1.10, TP12.TP, U2.21 (IO23)
FLASH_CS: D9.1, R5.1, U1.1 (!CS), U2.12 (IO11)
GDR: J1.2, Q3.1 (G), R4.1
GND: BOOT_BUTTON.1, BOOT_BUTTON.2, C1.2, C1_BAT.2, C1_BAT1.2, C1_BAT2.2, C2.2, C2_BAT.2, C3.-, C4_USB.2, C5.2, C5_USB.2, C6.2, C7.2, C8.2, C9.2, C10.2, C10_SUPERCAP.1, CHANGE_BUTTON.1, CHANGE_BUTTON.2, C_DELAY.2, D1.2 (GND), D3.1 (K), D6.2, D8.2, D9.2, D10.2, D11.2, D12.2, EPD_C1.2, EPD_C2.2, EPD_C5.2, EPD_C6.2, EPD_C7.2, EPD_C8.2, EPD_C9.2, EPD_C10.2, EPD_C11.2, EPD_C12.2, IC1.3 (GND), IC4.2 (VSS), J1.8, J1.17, J1.MP1, J1.MP2, J2.A1, J2.A12, J2.B1, J2.B12, J2.MP1, J2.MP2, J2.MP3, J2.MP4, J3.1, J4.G1 (GND_1), J4.G2 (GND_2), J4.G3 (GND_3), J4.G4 (GND_4), J4.P6 (VSS), MCP73831.2 (VSS), R1_PWRUSB.1, R2.1, R2-USB.2, R2-USB1.1, R2_BAT.1, R4.2, RESET_BUTTON.1, RESET_BUTTON.2, SENSOR2.1 (GND), SENSOR2.5 (SDO), SENSOR2.7 (GND), SJ1.1, TP4.TP, TP5.TP, U1.4 (GND), U1.9 (EXP), U2.1 (GND), U2.28 (GND), U2.29_1 (GND), U2.29_2 (GND), U2.29_3 (GND), U2.29_4 (GND), U2.29_5 (GND), U2.29_6 (GND), U2.29_7 (GND), U2.29_8 (GND), U2.29_9 (GND), U3.13 (GND), U4.1 (CTG), U4.4 (GND), U4.6 (QSTRT), U4.9 (EP)
GPIO8: R1.2, U2.10 (IO8)
I2C_PW: C1.1, C2.1, R1_PINH.2, R2-PINH.2, SENSOR2.2 (CSB), SENSOR2.6 (VDDIO), SENSOR2.8 (VDD), U2.17 (IO19)
INT_RTC: R1_PINH1.1, TP15.TP, U2.8 (IO0), U3.3 (SQW/!INT)
IO/BOOT: BOOT_BUTTON.3, BOOT_BUTTON.4, C6.1, R_BOOT.2, U2.15 (IO9)
IO/CHANGE: C10.1, CHANGE_BUTTON.3, CHANGE_BUTTON.4, R_CHANGE.2, U2.23 (IO15)
MISO: D12.1, J4.P7 (DAT0), R8.1, TP6.TP, U1.2 (DO(IO1)), U2.27 (IO2)
MOSI: D11.1, J1.14, J4.P3 (CMD), R7.1, TP7.TP, U1.5 (DI(IO0)), U2.7 (IO7)
unnamed: J2.A5, R2-USB1.2
unnamed: J2.B5, R2-USB.1
unnamed: C1_BAT1.1, D2.1 (CATHODE), IC4.1 (VIN), IC4.3 (CE), Q1.2 (S)
unnamed: C4.1, D3.2 (A), D4.1 (K)
unnamed: C_DELAY.1, IC1.5 (CT)
unnamed: CHG_LED.C, R1_BAT.2
unnamed: MCP73831.1 (STAT), R1_BAT.1
unnamed: EPD_C1.1, J1.4
unnamed: MCP73831.5 (PROG), R2_BAT.2
unnamed: EPD_C2.1, J1.5
unnamed: D7.1 (CATHODE), R_CAPACITOR.1
unnamed: EPD_C8.1, J1.20
unnamed: EPD_C7.1, J1.19
unnamed: EPD_C6.1, J1.18
unnamed: EPD_C10.1, J1.22
unnamed: EPD_C12.1, J1.24
PREVGH: EPD_C9.1, J1.21
PREVGL: D4.2 (A), D5.1 (K), EPD_C11.1, J1.23
RESE: J1.3, Q3.2 (S), R3.1
RESE': R2.2, R3.2, SJ1.2
RESET: C5.1, IC1.1 (VOUT), RESET_BUTTON.3, RESET_BUTTON.4, R_RESET.2, U2.3 (EN)
RTC_RST: U2.16 (IO18), U3.4 (!RST)
RX: TP2.TP, U2.24 (RXD0/GPIO17)
SCK: D10.1, J1.13, J4.P5 (CLK), R6.1, TP8.TP, U1.6 (CLK), U2.6 (IO6)
SCL: J3.4, R2-PINH.1, SENSOR2.4 (SCK), U2.20 (IO22), U3.16 (SCL), U4.7 (SCL)
SDA: J3.3, R1_PINH.1, SENSOR2.3 (SDI), U2.19 (IO21), U3.15 (SDA), U4.8 (SDA)
SRC: C4.2, D5.2 (A), L1.1, Q3.3 (D)
SS_SD: D8.1, J4.P2 (CD/DAT3), R10.1, U2.4 (IO4)
TX: TP1.TP, U2.25 (TXD0/GPIO16)
USB_D+: D1.1 (I/O1_1), U2.14 (IO13)
USB_D-: D1.3 (I/O2_1), U2.13 (IO12)
VBAT: C2_BAT.1, MCP73831.3 (VBAT), Q1.3 (D), TP3.TP, U4.2 (CELL), U4.3 (VDD)
VBUS: C1_BAT.1, C4_USB.1, C5_USB.1, CHG_LED.A, D1.5 (VBUS), D2.2 (ANODE), MCP73831.4 (VIN), PFMF.050.1.2, Q1.1 (G), R1_PWRUSB.2, TP14.TP
VRTC: C8.1, C10_SUPERCAP.2, R_CAPACITOR.2, U3.14 (VBAT)
VUSB: J2.A4, J2.A9, J2.B4, J2.B9, PFMF.050.1.1

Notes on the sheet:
USB C connector & ESD protection
LDO Voltage Regulator
SD Card
Display Type Selector
E-Paper Drive Circuit
Li-Po Battery Charging Controller
ESP32 C6
E-Paper Display Header
EPD Power
Environmental Sensor BME688
BME688
RTC Module DS3231SN
Test Pads
Qwiic / Stemma QT
SPI ESD Protection Lines
External NOR Flash 64MB
Battery Charge Level
Voltage Supervisor + Reset & Boot / IO Button
OpenBook Schematic
drawn by: Gheorghe Razvan
DeskAssistant v19
DMG2305UX-7
SD0805S020S1R0

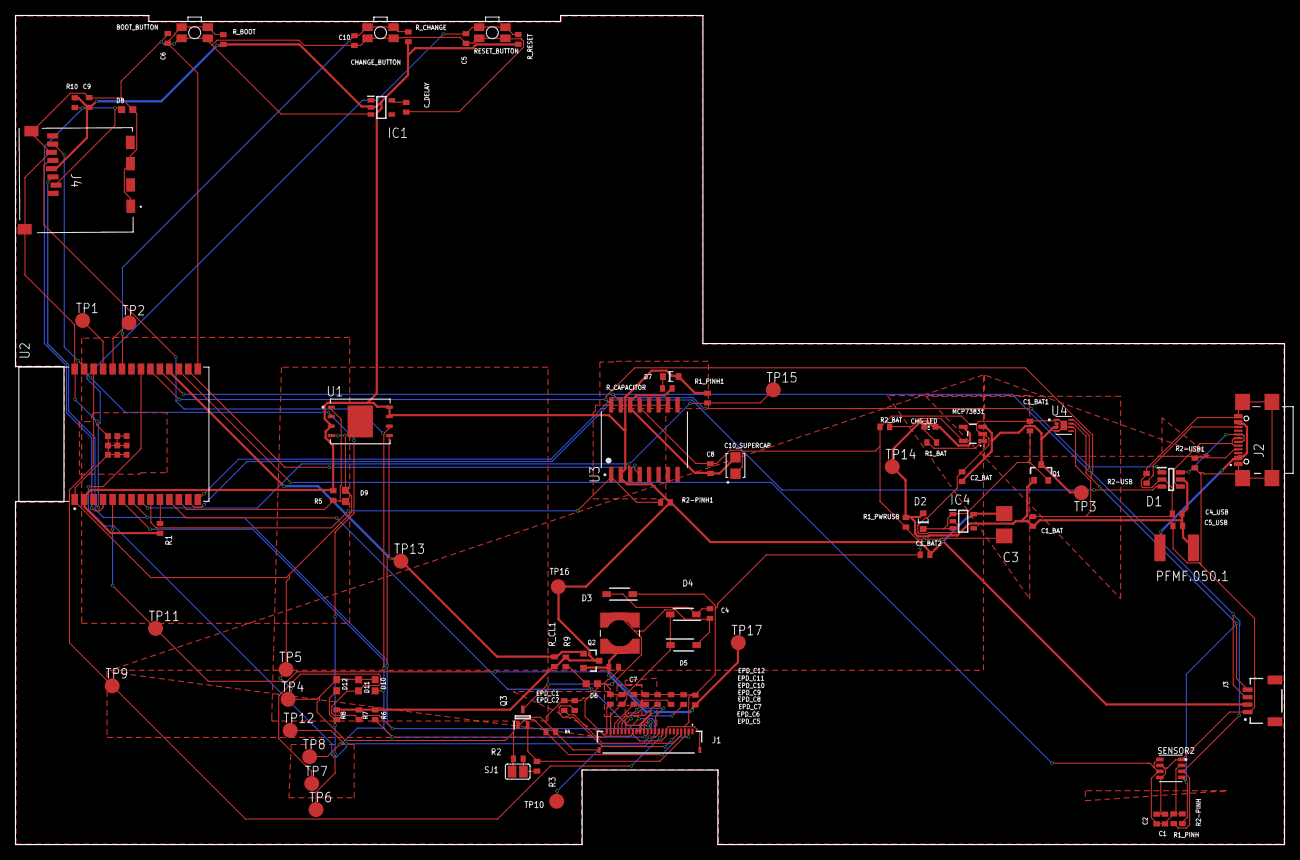
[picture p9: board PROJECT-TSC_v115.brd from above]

Board: 2 copper layers, 170.2 x 111.2 mm, 103 parts (0 on the bottom side), 55 nets.

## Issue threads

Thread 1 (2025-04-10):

Goluri in planul de masa

iamc03, 2025-04-10:
**Ai cateva spatii goale in planul de masa (spatiile cu albastru). Poti sa creezi via-uri pe care le legi de GND si le pui pe spatiile goale sau, mai simplu, faci Polygon Pour pe fiecare spatiu gol.**

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

Closed 2025-04-16.

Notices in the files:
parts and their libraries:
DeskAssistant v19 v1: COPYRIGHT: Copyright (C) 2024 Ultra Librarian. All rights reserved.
